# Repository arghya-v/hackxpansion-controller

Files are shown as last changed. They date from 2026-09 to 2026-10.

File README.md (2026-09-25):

# hackxpansion module 1: SD Card Reader and Volume Control

**Crates: pkg:cargo/SD_card_driver@0.1.1**

A custom SD card module with three buttons for music storage and controls, using Xpanse API for hardware/module integration.

# Images

final view

3d model

pcb
### Firmware

The firmware is responsible for communicating with the hardware.

The SD card is connected through SPI.

The current hardware mapping uses:

| GPIO  | Function |
| ----- | --- |
| GPIO2 | SPI SCK |
| GPIO3 | SPI MISO |
| GPIO4 | SPI MOSI |
| GPIO5 | Button A |
| GPIO6 | Button B |
| GPIO7 | Button X |
| GPIO9 | SD card CS |

See the [Xpanse API docs](https://docs.rs/xpanse-api/latest/xpanse_api/index.html)

---

## SD Card Filesystem

Its purpose is to abstract away the lower-level SD card communication so the application can work with files rather than dealing directly with SPI commands.

The filesystem layer provides functionality for:

* Opening the SD card
* Opening the first volume
* Opening the root directory
* Reading files
* Writing files
* Listing files in the root directory
* Closing directories and volumes

This is what the stack looks like:

```text
SD Card
   │
   ▼
  SPI
   │
   ▼
Xpanse SpiBusHandle
   │
   ▼
embedded-sdmmc
   │
   ▼
Filesystem
   │
   ▼
Application
```

This means the application itself does not need to know how the SD card communicates over SPI.

---

This was all possible thanks to [Hackspansion: A hackclub YSWS](http://hackxpansion.hackclub.com/)

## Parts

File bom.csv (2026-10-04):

Designator | Footprint | Quantity | Value | LCSC Part # | Price (USD)
J1 | Male_Module | 1 | Included in kit
J2 | C381082_TF-SMD_XKTF-015-N | 1 | Micro_SD_Card_Det1 | C381082 | 0.2892
R1 | 0805 | 1 | 1k | Included in kit
R2 | 0805 | 1 | 30k | Included in kit
R3, R4, R5 | 0805 | 3 | 10k | C140868 | 0.1580
SW1, SW2, SW3 | SW_PUSH_6mm | 3 | Included in kit
PCB |  |  | PCB |  | $4.00
PCBA Fee |  |  | PCBA Assembly |  | $17.39
Shipping |  |  | Shipping |  | $6.45
TOTAL |  |  |  |  | $28.00

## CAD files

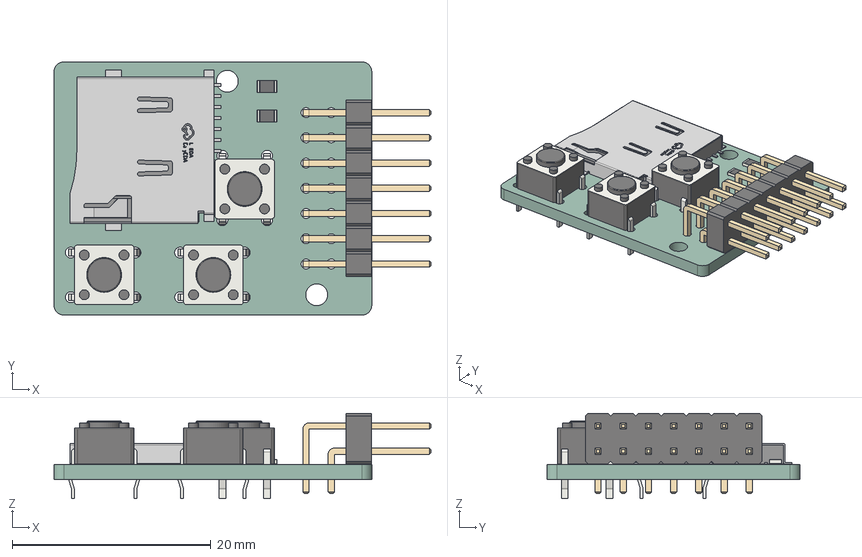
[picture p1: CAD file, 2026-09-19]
CAD/PCB.step
38.0 x 25.5 x 8.58 mm

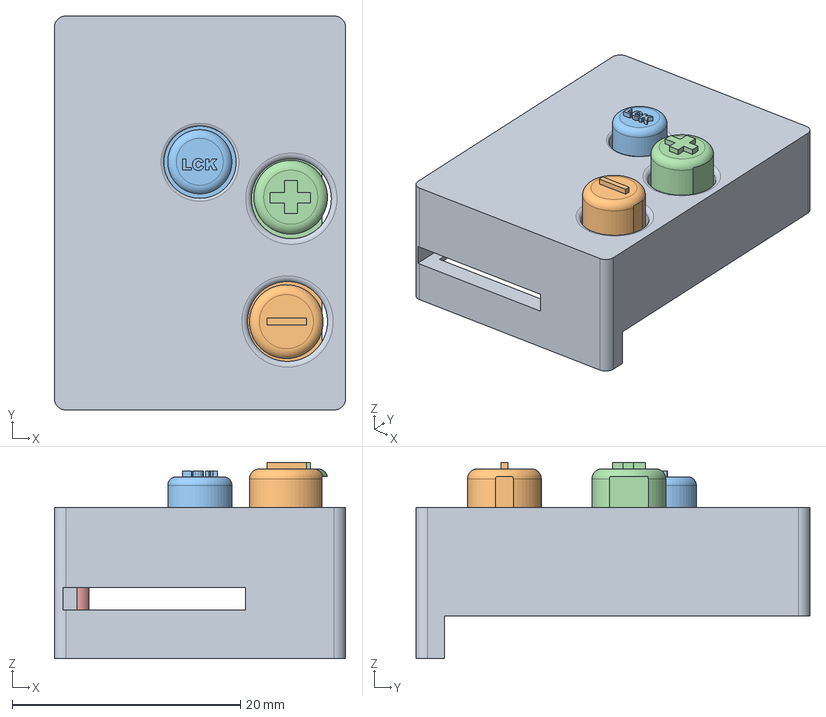
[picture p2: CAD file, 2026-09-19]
CAD/Module Case.step
25.5 x 34.5 x 17.2 mm

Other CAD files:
CAD/Module Case.f3z

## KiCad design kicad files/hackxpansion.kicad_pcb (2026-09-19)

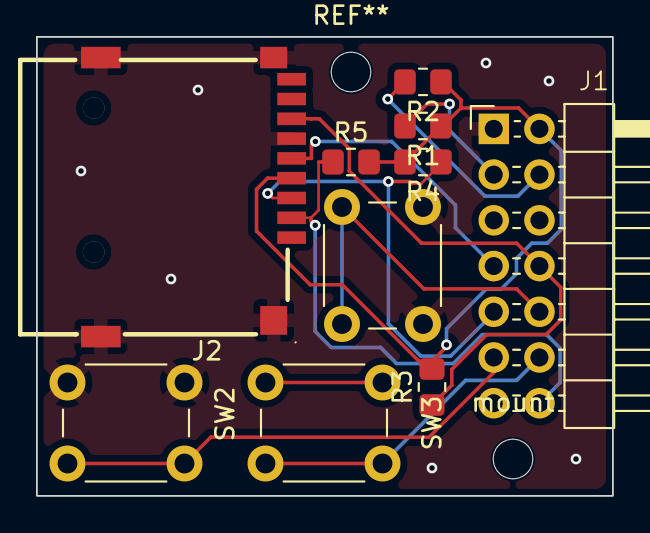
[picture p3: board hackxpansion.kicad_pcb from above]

Board: 2 copper layers, 32.0 x 25.5 mm, 11 parts (0 on the bottom side), 11 nets.

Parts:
J1: Male_Module
J2: Micro_SD_Card_Det1; C381082_TF-SMD_XKTF-015-N
R1: 1k; R_0805_2012Metric_Pad1.20x1.40mm_HandSolder
R2: 30k; R_0805_2012Metric_Pad1.20x1.40mm_HandSolder
R3, R4, R5: 10k; R_0805_2012Metric_Pad1.20x1.40mm_HandSolder
SW1, SW2, SW3: SW_Push; SW_PUSH_6mm
mount: MountingHole_2.2mm_M2

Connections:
+3V3: J1.2 (3V3), J2.4 (VDD), R1.1, R2.1, R3.2, R4.2, R5.2
/BTN1: J1.10 (GPIO5), SW1.1
/BTN2: J1.11 (GPIO6), SW2.1
/BTN3: J1.12 (GPIO7), SW3.1 (1_1)
/P2: J1.7 (GPI02), J2.5 (CLK)
/P3: J1.8 (GPIO3), J2.7 (DAT0), R3.1
/P4: J1.9 (GPIO4), J2.3 (CMD), R4.1
/P9: J1.14 (GPIO9), J2.2 (DAT3/CD), R5.1
GND: J1.1 (GND), J2.6 (VSS), J2.10 (GND), J2.11 (GND), J2.12 (GND), J2.13 (GND), SW1.2, SW2.2
unnamed: J1.3 (MD0), R1.2
unnamed: J1.4 (MD1), R2.2

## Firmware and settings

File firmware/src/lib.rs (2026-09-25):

#![no_std]
pub mod filesystem;

use embassy_rp::{
    bind_interrupts,
    gpio::{Level, Output},
    peripherals::{DMA_CH0, DMA_CH1},
    spi::{self},
};

use xpanse_api::{
    bus::{
        allocator::BusAllocator,
        spi::SpiBusHandle,
    },
    driver::{Driver, DriverError, DriverMeta},
    gpio_bank::{BankPins, GpioBank},
    interfaces::buttons::{pin_button, A, B, X},
    metadata::{ModuleDetectResistor, ModuleID, ModuleSlot},
    registry::Registry,
};

// Both DMA_CH0 and DMA_CH1 use DMA_IRQ_0 on the RP235x.
bind_interrupts!(pub struct Irqs {
    DMA_IRQ_0 =>
        embassy_rp::dma::InterruptHandler<DMA_CH0>,
        embassy_rp::dma::InterruptHandler<DMA_CH1>;
});

pub struct SdCard {
    pub spi: SpiBusHandle,
    pub cs: Output<'static>,
}

pub struct SdCardDriver;

impl DriverMeta for SdCardDriver {
    const ID: ModuleID = ModuleID {
        md0: ModuleDetectResistor::R1K,
        md1: ModuleDetectResistor::R30K,
    };
}

impl<G> Driver<G> for SdCardDriver
where
    G: BankPins,
{
    async fn create(
        gpio_bank: GpioBank<G>,
        slot: ModuleSlot,
        registry: &mut Registry,
        bus_allocator: &mut BusAllocator,
    ) -> Result<(), DriverError> {

        // -------------------------
        // Buttons
        // -------------------------

        registry.register(
            slot,
            Self::ID,
            pin_button::<A>(gpio_bank.gpio5.into()),
        );

        registry.register(
            slot,
            Self::ID,
            pin_button::<B>(gpio_bank.gpio6.into()),
        );

        registry.register(
            slot,
            Self::ID,
            pin_button::<X>(gpio_bank.gpio7.into()),
        );

        // -------------------------
        // SPI
        //
        // GPIO2 = SCK
        // GPIO3 = MISO
        // GPIO4 = MOSI
        // GPIO9 = CS
        // -------------------------

        let spi = bus_allocator
            .create_spi_hardware::<G::SPI, DMA_CH0, DMA_CH1, _>(
                gpio_bank.gpio2, // SCK
                gpio_bank.gpio4, // MOSI
                gpio_bank.gpio3, // MISO
                Irqs,
                spi::Config::default(),
            )
            .map_err(|_| DriverError::InitFailed)?;

        // SD card chip select.
        //
        // SD cards are selected when CS is LOW, so we start
        // deselected with CS HIGH.
        let cs = Output::new(
            gpio_bank.gpio9,
            Level::High,
        );

        // -------------------------
        // Register SD card resource
        // -------------------------

        registry.register(
            slot,
            Self::ID,
            SdCard {
                spi,
                cs,
            },
        );

        Ok(())
    }
}

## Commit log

2026-08-25 driver work!
2026-08-28 DONE THE DRIVER
2026-09-01 Rename hackxpansion.kicad_pcb to kicad files/hackxpansion.kicad_pcb
    [hackxpansion.kicad_pcb]
2026-09-01 Rename hackxpansion.kicad_prl to kicad files/hackxpansion.kicad_prl
2026-09-01 Rename hackxpansion.kicad_sch to kicad files/hackxpansion.kicad_sch
    [hackxpansion.kicad_sch]
2026-09-01 Add pcb.step file to CAD directory
    [pcb.step]
2026-09-01 Rename hackxpansion-NPTH.drl to drill files/hackxpansion-NPTH.drl
    [hackxpansion-NPTH.drl]
2026-09-01 Rename hackxpansion-PTH.drl to drill files/hackxpansion-PTH.drl
    [hackxpansion-PTH.drl]
2026-09-19 Update PCB image link in README
2026-10-04 Revise BOM with prices and new entries
    Updated BOM to include pricing and additional components.
    [bom.csv]
2026-10-11 Modify BOM with new resistor values and total price
    Updated resistor values and prices in the BOM.
